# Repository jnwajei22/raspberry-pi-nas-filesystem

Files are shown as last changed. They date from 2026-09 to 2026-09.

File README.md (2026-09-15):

# Raspberry Pi NAS Filesystem

A custom Raspberry Pi 4-based network attached storage system built around a 3D-printed enclosure, a custom USB-to-NVMe carrier PCB, and 4 TB of M.2 NVMe storage.

The goal of this project is to build a compact personal file server from the enclosure up rather than relying on a prebuilt NAS chassis or external SSD enclosure.

## Project Goals

- Raspberry Pi 4B-based NAS
- 4 TB M.2 2280 NVMe storage
- Custom 90 × 90 mm USB-to-NVMe carrier PCB
- USB 3.x connection between the Raspberry Pi and storage board
- Custom 3D-printed enclosure
- Internal mounting system for the Raspberry Pi, storage board, and cooling hardware
- Active cooling
- Small system-status display
- Local monitoring of:
  - CPU temperature
  - CPU usage
  - RAM usage
  - SSD usage
  - SSD temperature and health
  - Read/write activity
  - Network throughput
  - IP address
  - System uptime
  - File-transfer progress

## System Architecture

```text
                  ┌─────────────────────┐
                  │   Raspberry Pi 4B   │
                  │                     │
                  │   NAS / monitoring  │
                  └──────────┬──────────┘
                             │
                          USB 3.x
                             │
                             ▼
                  ┌─────────────────────┐
                  │ Custom NVMe Carrier │
                  │     90 × 90 mm      │
                  │                     │
                  │ USB-C               │
                  │   │                 │
                  │   ▼                 │
                  │ JMS583 Bridge       │
                  │   │                 │
                  │   ▼ PCIe Gen3 ×2    │
                  │ M.2 M-Key Socket    │
                  │   │                 │
                  │   ▼                 │
                  │ 4 TB NVMe SSD       │
                  └─────────────────────┘
```

## Hardware

### Raspberry Pi

The system is based on a Raspberry Pi 4B.

The Pi handles:

- network file sharing
- storage management
- system monitoring
- status-display output
- fan control
- file-transfer monitoring

### Storage

The original concept used raw NAND flash with a custom SSD controller. That architecture was replaced with a standard M.2 NVMe SSD to reduce firmware, NAND-management, and supply-chain complexity.

The current design uses:

- standard M.2 2280 form factor
- M-key NVMe SSD
- target capacity: 4 TB
- PCIe-to-USB bridge
- USB 3.x connection to Raspberry Pi 4B

### Custom NVMe Carrier PCB

Target specifications:

| Parameter | Specification |
|---|---|
| Board size | 90 × 90 mm |
| Layers | 4 |
| SSD | M.2 2280 NVMe |
| Interface | PCIe Gen3 ×2 to USB 3.x |
| Host connector | USB-C |
| SSD power | 3.3 V |
| Input power | 5 V |
| Auxiliary power | Optional 5 V input |

Current primary components:

| Function | Part |
|---|---|
| USB/NVMe bridge | JMicron JMS583 |
| M.2 socket | TE Connectivity 1-2199230-6 |
| USB-C receptacle | Molex 2024100002 |
| SSD regulator | TI TPS54302 |
| SPI configuration flash | Winbond W25Q40JV |
| High-speed ESD protection | TI TPD4E05U06 |
| Bridge clock | 25 MHz crystal |

The PCB is being designed in Autodesk Fusion Electronics.

## Enclosure

The enclosure was designed from scratch in Autodesk Fusion.

The design includes:

- Raspberry Pi mounting
- internal mounting plate
- upper hardware level
- SSD carrier PCB mounting
- ventilation on multiple enclosure walls
- active cooling
- removable lid
- locating lip for lid alignment
- provision for a front-mounted system-status display

The enclosure is intended to be fully 3D printed.

Source CAD and manufacturing exports are stored under:

```text
hardware/enclosure/
```

## Repository Structure

```text
raspberry-pi-nas-filesystem/
├── README.md
│
├── hardware/
│   ├── pcb/
│   │   ├── schematic/
│   │   ├── board/
│   │   ├── bom/
│   │   └── fabrication/
│   │
│   └── enclosure/
│       ├── fusion/
│       ├── exports/
│       │   ├── step/
│       │   ├── stl/
│       │   └── 3mf/
│       ├── drawings/
│       └── print-settings/
│
├── software/
│   ├── display/
│   ├── monitoring/
│   └── nas/
│
└── docs/
```

## Current Status

- [x] Raspberry Pi 4B selected
- [x] Enclosure concept completed
- [x] Internal mounting system modeled
- [x] Ventilation modeled
- [x] Main enclosure sent to print
- [x] Storage architecture selected
- [x] 4 TB M.2 NVMe target selected
- [x] Custom 90 × 90 mm carrier PCB architecture selected
- [ ] NVMe carrier schematic
- [ ] PCB layout
- [ ] PCB fabrication
- [ ] SSD installation
- [ ] Enclosure assembly
- [ ] Cooling installation
- [ ] Status display installation
- [ ] NAS operating-system configuration
- [ ] Monitoring software
- [ ] File-transfer progress display
- [ ] Final testing

## Design Philosophy

The project is intentionally designed as a complete engineering system rather than a collection of off-the-shelf modules.

Where practical, mechanical structure, mounting hardware, electronics, and software are being designed together so that the final system behaves as a single integrated device.

At the same time, standard components such as the Raspberry Pi and M.2 NVMe SSD are used where designing replacements would add significant complexity without improving the final NAS.

## Software

Planned software functions include:

- SMB/NFS file sharing
- storage-health monitoring
- NVMe SMART telemetry
- CPU and memory monitoring
- network throughput monitoring
- fan status/control
- local status-display interface
- transfer-progress visualization

Software development will be added after the mechanical and storage hardware are validated.

## CAD and Manufacturing Files

The repository will contain both editable source files and manufacturing exports.

For the enclosure:

- Fusion source files
- STEP files
- STL files
- 3MF files
- drawings
- print settings

For the PCB:

- Fusion Electronics schematic
- board layout
- BOM
- Gerbers
- drill files
- fabrication notes

## Revision

Current hardware revision:

```text
Enclosure: Rev A
NVMe Carrier PCB: Rev A
```

## Author

Justin Nwajei

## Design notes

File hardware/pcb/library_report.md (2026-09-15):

# KiCad library preparation report

Prepared 2026-09-14 and corrective-review updated 2026-09-15. The reviewed schematic is under `hardware/pcb/kicad/`.

All usable symbols, footprints, and 3D models are stored under `hardware/pcb/libraries/`. The project-local `sym-lib-table` and `fp-lib-table` use `${KIPRJMOD}` paths and do not reference global computer paths.

## Acquisition and verification status

| Part number | Manufacturer | Symbol source | Footprint source | Datasheet source | Exact-match status | Verification status | Notes |
|---|---|---|---|---|---|---|---|
| JMS583-QHFA0A | JMicron | **CUSTOM-VERIFY**, drawn from the public JMicron JMS583 Rev. 2.1 signal table | Exact EasyEDA/LCSC record C9900110183, component UUID `7ed4b3711810454eb69c8505d68afa0a`, footprint UUID `2eb720523592401281967fab13173877`; converted to KiCad | [JMicron JMS583 Rev. 2.1 public datasheet](https://snapeda.s3.amazonaws.com/datasheets/2115-PDS-17001_JMS583_Datasheet_(Rev._2.1)_20190716.pdf); local copy `libraries/datasheets/JMicron_JMS583_datasheet_rev2.1.pdf` | YES for ordering code and exact distributor CAD record | **CUSTOM-VERIFY** | Symbol has pins 1-64 plus exposed pad 65. Footprint is QFN-64, 8.0 x 8.0 mm, 0.40 mm pitch, with 4.5 x 4.5 mm exposed pad 65 and 65 total pads. Pin 65 is explicitly grounded in the corrected schematic. Exact converted STEP is local. |
| 2024100002 | Molex | Official KiCad `USB_C_Receptacle` pin model adapted to the exact MPN and local footprint | Exact EasyEDA/LCSC C586089 CAD, converted to KiCad | [Molex exact product page](https://www.molex.com/en-us/products/part-detail/2024100002), [customer drawing 2024100002](https://www.molex.com/content/dam/molex/molex-dot-com/products/automated/en-us/salesdrawingpdf/202/202410/2024100002_sd.pdf) | YES | **CUSTOM-VERIFY symbol; VERIFIED footprint** | 24 USB-C contacts A1-A12/B1-B12 at 0.50 mm pitch. Four shell/retention pads are all numbered `S1` to match the symbol shield pin. Mid-mount outline, connector orientation, shell holes/tabs, and 0.60/0.70 mm PCB-thickness callout were checked. Exact converted STEP is local. |
| 1-2199230-6 | TE Connectivity | Official KiCad `Bus_M.2_Socket_M` adapted to exact MPN; explicit `SH1`/`SH2` shield pins added | Exact EasyEDA/LCSC C4710843 CAD, converted to KiCad | [TE exact product page](https://www.te.com/fr/product-1-2199230-6.html), [TE customer drawing mirror](https://www.farnell.com/cad/1918022.pdf) | YES | **CUSTOM-VERIFY symbol; VERIFIED footprint** | M-key, 67 signal contacts: 1-58 and 67-75, 0.50 mm pitch; 2 SMD shield tabs `SH1`/`SH2`; 2 unnumbered NPTH locator holes. Keying, orientation, 21.9 x 8.7 x 4.2 mm product envelope, and mounting features checked. Exact converted STEP is local. |
| TPS54302DDCR | Texas Instruments | Official KiCad `TPS54302`, adapted to exact ordering code and local footprint | Official KiCad `SOT-23-6`, copied locally as `TPS54302DDCR_DDC0006A` | [TI exact part page](https://www.ti.com/product/TPS54302/part-details/TPS54302DDCR), [TI TPS54302 datasheet](https://www.ti.com/lit/ds/symlink/tps54302.pdf); local copy `libraries/datasheets/TI_TPS54302_datasheet.pdf` | YES | **VERIFIED** | Pins verified: 1 GND, 2 SW, 3 VIN, 4 FB, 5 EN, 6 BOOT. DDC0006A/SOT-23-6 has 6 pads, 0.95 mm pitch, no exposed pad. Official KiCad package STEP is copied locally. |
| W25Q16JVSNIQ (tape/reel order option `W25Q16JVSNIQ TR`) | Winbond | Official KiCad W25Q-JV pin model, flattened and adapted to the exact orderable package suffix | Official KiCad `SOIC-8_3.9x4.9mm_P1.27mm`, copied locally as `Winbond_W25Q16JVSNIQ_SOIC8_150mil` | [Winbond W25Q16JV documentation](https://www.winbond.com/hq/support/documentation/levelOne.jsp?__locale=en&DocNo=DA00-W25Q16JV.1), [Winbond W25Q-JV family](https://www.winbond.com/hq/product/code-storage-flash/qspi-nor/w25q-jv/?__locale=en), [active stocked tape/reel listing](https://www.digikey.com/en/products/detail/winbond-electronics/W25Q16JVSNIQ-TR/10238303) | YES | **VERIFIED** | Replaces invalid `W25Q40JVSSIQ`. 16 Mbit / 2 MiB, 2.7-3.6 V, SPI/Dual/Quad SPI, SOIC-8 150 mil, -40 to +85 C. Pins: 1 CS#, 2 DO/IO1, 3 WP#/IO2, 4 GND, 5 DI/IO0, 6 CLK, 7 HOLD#/RESET#/IO3, 8 VCC. Eight pads, 1.27 mm pitch, 3.9 x 4.9 mm body, no exposed pad. The older 8 Mbit JV SOIC and the 208 mil W25Q16JVSSIQ were rejected because they are marked obsolete; the W25Q16JVSNIQ tape/reel listing is active and stocked. |
| TPD4E05U06DQAR | Texas Instruments | Official KiCad `TPD4EUSB30` pin-compatible device symbol adapted to the exact MPN | Official KiCad `USON-10_2.5x1.0mm_P0.5mm`, copied locally as `TPD4E05U06DQAR_DQA0010A` | [TI exact part page](https://www.ti.com/product/TPD4E05U06/part-details/TPD4E05U06DQAR), [TI TPD4E05U06 datasheet](https://www.ti.com/lit/ds/symlink/tpd4e05u06.pdf); local copy `libraries/datasheets/TI_TPD4E05U06_datasheet.pdf` | YES | **VERIFIED with package-construction note** | Pins verified: 1 D1+, 2 D1-, 3 GND, 4 D2+, 5 D2-, 6 NC, 7 NC, 8 GND, 9 NC, 10 NC. DQA is USON-10, 2.5 x 1.0 mm, 0.50 mm pitch, 10 pads, no center exposed pad in DQA0010A. Official KiCad package STEP is copied locally. |
| ABM8-25.000MHZ-B2-T | Abracon | Official KiCad `Crystal_GND24` adapted to the exact MPN and local footprint | Exact EasyEDA/LCSC C596899 CAD, converted to KiCad | [Abracon ABM8 datasheet](https://abracon.com/Resonators/abm8.pdf); local copy `libraries/datasheets/Abracon_ABM8_datasheet.pdf` | YES | **CUSTOM-VERIFY symbol; VERIFIED footprint** | Four pads: 1/3 crystal electrodes and 2/4 case ground. Verified 3.2 x 2.5 x 0.8 mm body and recommended pads 1.4 x 1.2 mm centered at +/-1.10 mm X and +/-0.85 mm Y. Exact converted STEP is local. |

## Verification details

### Symbol pin checks

- `JMicron_JMS583-QHFA0A`: checked all numbered pins 1-64 against the Rev. 2.1 signal table, including USB SuperSpeed pairs (`U_TXP/N1`, `U_TXP/N2`, `U_RXP/N1`, `U_RXP/N2`), PCIe pairs (`P_TXP/N0`, `P_TXP/N1`, `P_RXP/N0`, `P_RXP/N1`), USB 2.0 `DP`/`DM`, `CLKP`/`CLKN`, `CC1`/`CC2`, rails, reset, GPIO, crystal, and regulator pins. Pad 65 is exposed as `EP` so the footprint cannot silently contain an unmapped electrical pad.
- `Molex_2024100002`: verified the complete reversible USB-C receptacle pin set A1-A12/B1-B12, duplicated VBUS/GND pins, USB 2.0 D+/D- pins, SuperSpeed TX/RX pairs, CC1/CC2, SBU1/SBU2, and shield.
- `TE_1-2199230-6`: verified M-key contact numbering and omitted key positions. Both footprint shell pads are now explicit passive symbol pins `SH1` and `SH2`.
- `TPS54302DDCR`, `TPD4E05U06DQAR`, and `ABM8-25.000MHZ-B2-T`: pin numbers and functions match the manufacturer pin diagrams/tables summarized above.
- `W25Q16JVSNIQ`: verified against the Winbond pin diagram and official KiCad model: 1 CS#, 2 DO/IO1, 3 WP#/IO2, 4 GND, 5 DI/IO0, 6 CLK, 7 HOLD#/RESET#/IO3, and 8 VCC.

### Footprint mechanical checks

| Local footprint | Pad records | Mechanical verification |
|---|---:|---|
| `JMicron_JMS583-QHFA0A.kicad_mod` | 65 | QFN-64, 16 perimeter pads per side, 0.40 mm pitch, 8 x 8 mm body, center exposed pad 65 |
| `Molex_2024100002.kicad_mod` | 28 | 24 signal contacts plus four shell/retention tabs; exact mid-mount cutout and locator features retained |
| `TE_1-2199230-6_M2_M_Key.kicad_mod` | 71 | 67 signal contacts, two shield tabs, and two unnumbered NPTH locator holes; M-key gap retained |
| `TPS54302DDCR_DDC0006A.kicad_mod` | 6 | TI DDC/SOT-23-6, 0.95 mm pitch, no exposed pad |
| `TPD4E05U06DQAR_DQA0010A.kicad_mod` | 10 | TI DQA0010A USON-10, 2.5 x 1.0 mm, 0.50 mm pitch |
| `Abracon_ABM8-25.000MHZ-B2-T.kicad_mod` | 4 | 3.2 x 2.5 mm crystal, correct four-pad geometry and pin-1 marker |
| `Winbond_W25Q16JVSNIQ_SOIC8_150mil.kicad_mod` | 8 | SOIC-8 150 mil, 3.9 x 4.9 mm body, 1.27 mm pitch, no exposed pad; pad 1 marker retained |

## Sources and provenance

- Generic symbol/package bases are from the installed KiCad 9 official libraries and were copied into this repository: [KiCad symbols](https://gitlab.com/kicad/libraries/kicad-symbols) and [KiCad footprints](https://gitlab.com/kicad/libraries/kicad-footprints).
- Exact distributor CAD for JMS583-QHFA0A, 2024100002, 1-2199230-6, and ABM8-25.000MHZ-B2-T was converted to native KiCad format. Exact source UUID records retained for JMS583 are in `libraries/datasheets/source_records/`.
- Every footprint's 3D reference uses `${KIPRJMOD}/../libraries/3dmodels/...` from the requested `hardware/pcb/kicad/` project directory; no global KiCad or arbitrary machine path is used.

## Uncertainties and release gates

1. **JMS583 exposed pad:** pin 65 `EP` is explicitly connected to GND, matching the grounded center pad used by the available JMS583 package/reference guidance. This connection must be implemented with an appropriate thermal/via structure during layout.
2. **TPD4E05U06 DQA construction:** TI documents DQA0010A and DQA0010B package constructions for this orderable part. The local footprint is explicitly DQA0010A. TI support describes the constructions as interchangeable, but DQA0010B bridges the two GND lead regions. Confirm assembly-land-pattern acceptance if the fabricator requires construction-specific paste/copper details: [TI package discussion](https://e2e.ti.com/support/interface-group/interface/f/interface-forum/1384139/tpd4e05u06-what-is-the-correct-package-drawing).
3. **JMS583 application circuits:** the corrective review now uses 1.0 V for every VCCK/AVDDL pin, a 4.7 uH LXO inductor, a 330 kΩ/1 uF reset RC, 30 pF crystal loads plus 510 kΩ XIN-XOUT bias, grounded TME/EPAD, a GPIO4 active-low LED, and a GPIO6 VBUS divider. Crystal parasitics and final passive selections remain release checks.
4. **M.2 connector ERC typing repair:** signal pins on the adapted connector were changed from input/output/bidirectional to passive. Pin names, pin numbers, keying and footprint pads are unchanged. This correctly models a connector and removes false driver conflicts.
5. Symbols labeled **CUSTOM-VERIFY** were created or adapted from public documentation because a directly downloadable, authoritative exact-MPN KiCad symbol was not available. They have been checked as documented but should receive an independent engineering review before fabrication.

## Final status

- **Exact libraries acquired:** JMS583-QHFA0A, Molex 2024100002, TE 1-2199230-6, TPS54302DDCR, TPD4E05U06DQAR, and Abracon ABM8-25.000MHZ-B2-T.
- **Flash substitution:** invalid `W25Q40JVSSIQ` replaced by verified, active/stocked tape-reel `W25Q16JVSNIQ`.
- **Parts missing:** none among the seven required exact parts.
- **Custom libraries created/adapted and labeled CUSTOM-VERIFY:** JMS583-QHFA0A symbol; Molex 2024100002 symbol adaptation; TE 1-2199230-6 symbol adaptation including shield pins; Abracon ABM8-25.000MHZ-B2-T symbol adaptation.
- **Pinout/package uncertainties:** TPD4E05U06 DQA0010A versus DQA0010B construction remains; JMS583 EPAD is now explicitly grounded and its thermal/via implementation remains a layout requirement.
- **Repository-local KiCad tables ready:** YES. The project tables in `hardware/pcb/kicad/` use `${KIPRJMOD}/../libraries/...`; the library-root tables remain valid for `hardware/pcb/`.
- **Library parser validation:** KiCad 9.0.5 successfully exported the W25Q16JVSNIQ symbol and footprint to SVG.
- **Schematic validation:** after the 2026-09-15 corrective review, KiCad 9.0.5 parses and exports netlist/BOM/PDF/SVG and reports **0 ERC errors and 0 ERC warnings**.

## Corrected schematic summary

The single A3 schematic is divided into four labeled sections: USB interface, JMS583 bridge, NVMe/M.2, and power. It contains the exact USB-C receptacle, JMS583, M.2 socket, TPS54302, crystal, flash and three TPD4E05U06 arrays. Four 100 nF capacitors couple the JMS583 USB transmitter pairs, and four 220 nF capacitors couple the JMS583 PCIe transmit lanes. Only PCIe lanes 0 and 1 are connected; lanes 2 and 3 are explicitly unconnected. The ESD arrays are shunt branches from continuous connector-side USB nets and are not series elements.

The former U5 power-mux placeholder has been removed. `USB5V` powers the JMS583 VDDREG/VBUS side and its internally generated 3.3 V/1.0 V rails; `AUX5V` independently powers the TPS54302 and NVMe 3.3 V rail; grounds are common. AUX5V/3V3_NVME must be ready before enumeration when SSD access is required. The TPS54302 network retains TI's 3.3 V starting values: 6.8 uH, 44 uF nominal output capacitance, 100 kΩ / 22.1 kΩ feedback and 47 pF feed-forward. The regulator's 3 A maximum is a release gate until the 4 TB SSD is selected.

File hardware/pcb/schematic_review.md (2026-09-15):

# Corrective schematic review

Reviewed and regenerated 2026-09-15. Scope is schematic only; no PCB layout was created or started.

## Validation result

- KiCad version: 9.0.5
- ERC: 0 errors, 0 warnings (`kicad/erc.json`)
- Netlist export: successful (`kicad/raspberry_pi_nas_nvme.net`)
- BOM export: successful (`kicad/raspberry_pi_nas_nvme_bom.csv`)
- PDF export: successful (`kicad/raspberry_pi_nas_nvme_review.pdf`)
- SVG export: successful (`kicad/raspberry_pi_nas_nvme.svg`)

## 1. JMS583 supply correction

The incorrect `1V2_JMS` rail was removed everywhere and replaced by `1V0_JMS`.

| JMS583 pins | Function | Corrected net |
|---|---|---|
| 2, 31, 53 | VCCK, digital core | `1V0_JMS` |
| 20, 25, 30, 33, 36, 40, 43, 46, 49 | AVDDL, analog core | `1V0_JMS` |
| 6, 11, 32, 56 | VCCO, 3.3 V I/O | `3V3_JMS` |
| 52 | XAVDDH, crystal pad supply | `3V3_JMS` |
| 64 | LXO switching node | `JMS_LXO` → L1 4.7 µH → `1V0_JMS` |
| 1 | VDDREG, internal-regulator 5 V input | `USB5V` |
| 19 | AVDD33, internal 3.3 V output | `3V3_JMS` |

The 1.0 V bypass network is C8 = 100 nF, C9 = 1 µF and C10 = 4.7 µF. Final distribution and per-pin capacitor placement must be completed during layout.

## 2. Reset RC

The former pull-up-only reset was electrically incomplete. RST pin 15 now has:

- R2 = 330 kΩ, 1%, from `3V3_JMS` to `JMS_RST_N`
- C26 = 1 µF, X7R, 10%, from `JMS_RST_N` to GND

The JMS583 datasheet defines T4 as the RST rise time from 0 V to 1.77 V and requires 120–500 ms for an RC implementation. For a 3.3 V exponential charge:

`t = -RC × ln(1 - 1.77/3.3) = 0.768RC`

Nominally, `t = 0.768 × 330 kΩ × 1 µF = 254 ms`. With the stated resistor and capacitor tolerances, the component-tolerance range is approximately 226–282 ms, inside the documented 120–500 ms interval. Capacitor leakage and effective capacitance must be checked when selecting the exact C26 MPN.

## 3. Crystal network

Y1 remains the ABM8-25.000MHZ-B2-T: 25 MHz, specified load capacitance 18 pF. The completed network is:

- C24 = 30 pF C0G 5% from XIN to GND
- C25 = 30 pF C0G 5% from XOUT to GND
- R8 = 510 kΩ from XIN to XOUT, following the JMS583 reference topology
- Crystal case pads 2 and 4 to GND

For equal load capacitors, `CL = C/2 + Cstray`. Using a documented design assumption of 3 pF combined IC-pin/trace/land stray capacitance gives `CL = 30/2 + 3 = 18 pF`. This is a calculated starting network, not an arbitrary value. Actual parasitics depend on placement and routing, so C24/C25 must be revisited using extracted or measured board parasitics before release.

## 4. USB ESD audit

The existing TPD4E05U06 signal implementation was **not electrically wrong**. Each channel was already a shunt branch from a signal net to the ESD device, with pins 3 and 8 grounded. No ESD device was placed in series. The corrected schematic preserves that topology.

| Protected net | Continuous signal path | ESD branch |
|---|---|---|
| `USB_TX1_P/N` | J1 A2/A3 directly to U1 U_RXP1/U_RXN1 pins 26/27 | U2 pins 1/2 |
| `USB_TX2_P/N` | J1 B2/B3 directly to U1 U_RXP2/U_RXN2 pins 29/28 | U3 pins 1/2 |
| `USB_RX1_P/N` | J1 B11/B10 to C1/C2; capacitor inner nets go to U1 U_TXP1/U_TXN1 pins 21/22 | U2 pins 4/5 on connector side |
| `USB_RX2_P/N` | J1 A11/A10 to C3/C4; capacitor inner nets go to U1 U_TXP2/U_TXN2 pins 24/23 | U3 pins 4/5 on connector side |
| `USB_DP/DM` | J1 A6/B6 and A7/B7 directly to U1 DP/DM pins 18/17 | U4 pins 1/2 |

U4's unused channels are no-connect. All three devices connect both ground pins, 3 and 8, to common GND. The physical placement/routing requirement remains: place the ESD arrays close to J1 with a short, low-inductance ground return and avoid stubs on the SuperSpeed pairs.

## 5. Split power architecture

The unresolved U5 power-mux placeholder was removed. The schematic now implements:

- `USB5V` from J1 powers JMS583 VDDREG pin 1 and VBUS pin 16.
- The JMS583 generates its local `3V3_JMS` and `1V0_JMS` rails.
- `AUX5V` from J2 powers TPS54302 VIN and EN plus its input capacitors.
- TPS54302 generates `3V3_NVME` only for the M.2/NVMe load.
- USB and auxiliary supplies share GND but are not tied together on their positive rails.

This split is valid provided AUX5V and `3V3_NVME` are stable when the bridge enumerates and attempts to discover the SSD. If AUX5V can arrive later than USB5V, system-level sequencing or a re-enumeration/reset policy is required.

USB cable presence is handled in both documented ways: U1 VBUS pin 16 is tied to USB5V, and GPIO6 pin 10 receives `USB_VBUS_SENSE` through a 100 kΩ/100 kΩ divider. The nominal GPIO6 level is 2.5 V at 5.0 V VBUS.

## 6. PCIe topology

PCIe lanes 0 and 1 remain connected for x2 operation. Lanes 2 and 3 remain intentionally unconnected. C11–C14 remain 220 nF series capacitors on the two JMS583 PCIe transmit differential pairs. No topology change was made.

## 7. TPS54302 review

The TI 3.3 V starting network remains unchanged:

- L2 = 6.8 µH
- C20 + C21 = 44 µF nominal output capacitance
- R6/R7 = 100 kΩ / 22.1 kΩ
- C19 = 47 pF feed-forward

The TPS54302's 3 A maximum is a release gate. The actual 4 TB NVMe SSD must be selected and its startup, peak and transient current verified before release. Effective ceramic output capacitance under 3.3 V DC bias must also meet the regulator stability/transient requirements.

## 8. EPAD and test mode

- U1 exposed pad pin 65 is explicitly tied to GND.
- U1 ground pin 63 is tied to GND.
- U1 TME pin 60 is tied to GND, holding test mode at logic 0 for normal operation.

The eventual layout must use the exposed-pad copper/via pattern required for electrical grounding and thermal performance.

## 9. Activity LED correction

The previous schematic was electrically wrong here: D1 was connected to GPIO12, pin 57. It is now connected to the documented default LED output, GPIO4 pin 8.

The corrected active-low sink path is `3V3_JMS → R3 (1 kΩ) → D1 anode → D1 cathode → GPIO4`. GPIO12 is no-connect. The exact LED MPN and brightness remain component-selection items.

## Remaining release gates

- Select the exact J2 connector and define the AUX5V source requirements.
- Select and derate every generic passive, inductor and LED.
- Confirm reset-capacitor leakage/effective capacitance with the selected MPN.
- Extract or measure the crystal network parasitics and tune C24/C25 if necessary.
- Define system sequencing behavior if AUX5V can be absent or late relative to USB5V.
- Select the 4 TB NVMe SSD and verify the TPS54302 3 A limit and transient response.

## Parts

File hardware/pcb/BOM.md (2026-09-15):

# Raspberry Pi NAS NVMe schematic BOM

Corrected schematic BOM for `hardware/pcb/kicad/raspberry_pi_nas_nvme.kicad_sch`, reviewed 2026-09-15. Quantities are per board. Generic passives retain package/value assignments but require final manufacturer-part selection and derating before PCB release.

## Exact and major parts

| References | Qty | Manufacturer | Manufacturer part number | Description | Footprint | Status |
|---|---:|---|---|---|---|---|
| U1 | 1 | JMicron | JMS583-QHFA0A | USB 3.x to PCIe/NVMe bridge | `RaspberryPiNAS:JMicron_JMS583-QHFA0A` | Exact; corrected 1.0 V rails, reset, crystal, VBUS sense, GPIO4 LED, TME and EPAD connections |
| J1 | 1 | Molex | 2024100002 | Full-featured USB-C receptacle | `RaspberryPiNAS:Molex_2024100002` | Exact, verified orientation/keying |
| J3 | 1 | TE Connectivity | 1-2199230-6 | 67-contact M.2 M-key socket | `RaspberryPiNAS:TE_1-2199230-6_M2_M_Key` | Exact, verified; PCIe Gen3 x2 electrically |
| U7 | 1 | Texas Instruments | TPS54302DDCR | 3 A synchronous buck regulator | `RaspberryPiNAS:TPS54302DDCR_DDC0006A` | Exact; AUX5V-powered 3.3 V NVMe supply |
| U2-U4 | 3 | Texas Instruments | TPD4E05U06DQAR | Four-channel low-capacitance shunt ESD array | `RaspberryPiNAS:TPD4E05U06DQAR_DQA0010A` | Exact; branched from continuous USB nets, never used in series |
| U6 | 1 | Winbond | W25Q16JVSNIQ TR | 16 Mbit, 3 V SPI/Dual/Quad NOR flash | `RaspberryPiNAS:Winbond_W25Q16JVSNIQ_SOIC8_150mil` | Exact verified replacement for invalid W25Q40JVSSIQ |
| Y1 | 1 | Abracon | ABM8-25.000MHZ-B2-T | 25 MHz, 18 pF load crystal | `RaspberryPiNAS:Abracon_ABM8-25.000MHZ-B2-T` | Exact; 30 pF calculated load capacitors and 510 kΩ bias resistor added |
| D1 | 1 | TBD | TBD | Green activity LED | `LED_SMD:LED_0603_1608Metric_Pad1.05x0.95mm_HandSolder` | Active-low: 3V3_JMS → R3 → anode/cathode → JMS583 GPIO4 |
| J2 | 1 | TBD | TBD | Auxiliary 5 V input connector | No footprint assigned | Powers only the TPS54302/NVMe rail; connector selection remains open |

## Resistors

| References | Qty | Value | Function | Footprint/status |
|---|---:|---|---|---|
| R1 | 1 | 12 kΩ, 1% | JMS583 REXT | 0603; documented value |
| R2 | 1 | 330 kΩ, 1% | JMS583 active-low reset pull-up | 0603; with C26 gives 254 ms nominal to 1.77 V |
| R3 | 1 | 1 kΩ | GPIO4 activity LED current limiting | 0603; active-low sink arrangement |
| R4-R5 | 2 | 10 kΩ | Flash WP#/HOLD# pull-ups | 0603 |
| R6 | 1 | 100 kΩ, 1% | TPS54302 upper feedback resistor | 0603; TI 3.3 V starting value |
| R7 | 1 | 22.1 kΩ, 1% | TPS54302 lower feedback resistor | 0603; TI 3.3 V starting value |
| R8 | 1 | 510 kΩ | Crystal XIN-to-XOUT bias/feedback | 0603; follows the JMS583 reference topology |
| R9-R10 | 2 | 100 kΩ, 1% | USB VBUS divider to GPIO6 | 0603; 5 V produces nominal 2.5 V sense level |

## Capacitors and inductors

| References | Qty | Value | Function | Footprint/status |
|---|---:|---|---|---|
| C1-C4 | 4 | 100 nF | JMS583 USB TX AC coupling | 0603; retained |
| C5, C8 | 2 | 100 nF | JMS583 3.3 V / 1.0 V high-frequency bypass | 0603 |
| C6, C9 | 2 | 1 µF | JMS583 3.3 V / 1.0 V local bypass | 0603 |
| C7, C10 | 2 | 4.7 µF | JMS583 3.3 V / 1.0 V bulk bypass | 0603; verify DC bias |
| C11-C14 | 4 | 220 nF | JMS583 PCIe TX coupling, lanes 0/1 | 0603; retained |
| C15 | 1 | 10 µF | TPS54302 AUX5V input decoupling | 1210; select voltage/ripple rating |
| C16 | 1 | 100 nF | TPS54302 AUX5V high-frequency bypass | 0603 |
| C17 | 1 | 47 µF | AUX5V bulk | 1210 placeholder; select rated part |
| C18 | 1 | 100 nF | TPS54302 BOOT-SW | 0603 |
| C19 | 1 | 47 pF | TPS54302 feed-forward | 0603; TI 3.3 V starting value |
| C20-C21 | 2 | 22 µF | TPS54302 output, 44 µF nominal total | 1210; verify effective capacitance under DC bias |
| C22 | 1 | 100 µF | M.2 3.3 V bulk | 1210 placeholder; package/technology may need enlargement |
| C23 | 1 | 100 nF | M.2 local high-frequency bypass | 0603 |
| C24-C25 | 2 | 30 pF, C0G, 5% | 25 MHz crystal load | 0603; calculated for 18 pF CL with 3 pF combined parasitic assumption |
| C26 | 1 | 1 µF, X7R, 10% | JMS583 reset timing capacitor | 0603; use a low-leakage part with adequate effective capacitance |
| L1 | 1 | 4.7 µH | JMS583 LXO to 1V0_JMS regulator inductor | 1210; select current-rated MPN |
| L2 | 1 | 6.8 µH, ≥3 A | TPS54302 3.3 V buck | 1210 placeholder; select saturation/current-rated MPN |

## Release gates

- Select a rated AUX5V connector and define the required source voltage/current tolerance.
- Select manufacturer part numbers for passives, inductors and LED after voltage, DC-bias, leakage, ripple, saturation, tolerance and thermal checks.
- Measure or extract actual crystal pin/trace parasitics during layout and tune C24/C25 if the assumed 3 pF is not valid.
- Confirm AUX5V and 3V3_NVME sequencing is valid before USB enumeration in the finished system.
- Confirm the selected 4 TB NVMe SSD's peak and transient current is compatible with the TPS54302's 3 A maximum.

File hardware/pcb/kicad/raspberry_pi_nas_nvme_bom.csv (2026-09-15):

Refs | Value | Footprint | Qty | DNP
C1 | 100nF | Capacitor_SMD:C_0603_1608Metric_Pad1.08x0.95mm_HandSolder | 1
C2 | 100nF | Capacitor_SMD:C_0603_1608Metric_Pad1.08x0.95mm_HandSolder | 1
C3 | 100nF | Capacitor_SMD:C_0603_1608Metric_Pad1.08x0.95mm_HandSolder | 1
C4 | 100nF | Capacitor_SMD:C_0603_1608Metric_Pad1.08x0.95mm_HandSolder | 1
C5 | 100nF | Capacitor_SMD:C_0603_1608Metric_Pad1.08x0.95mm_HandSolder | 1
C6 | 1uF | Capacitor_SMD:C_0603_1608Metric_Pad1.08x0.95mm_HandSolder | 1
C7 | 4.7uF | Capacitor_SMD:C_0603_1608Metric_Pad1.08x0.95mm_HandSolder | 1
C8 | 100nF | Capacitor_SMD:C_0603_1608Metric_Pad1.08x0.95mm_HandSolder | 1
C9 | 1uF | Capacitor_SMD:C_0603_1608Metric_Pad1.08x0.95mm_HandSolder | 1
C10 | 4.7uF | Capacitor_SMD:C_0603_1608Metric_Pad1.08x0.95mm_HandSolder | 1
C11 | 220nF | Capacitor_SMD:C_0603_1608Metric_Pad1.08x0.95mm_HandSolder | 1
C12 | 220nF | Capacitor_SMD:C_0603_1608Metric_Pad1.08x0.95mm_HandSolder | 1
C13 | 220nF | Capacitor_SMD:C_0603_1608Metric_Pad1.08x0.95mm_HandSolder | 1
C14 | 220nF | Capacitor_SMD:C_0603_1608Metric_Pad1.08x0.95mm_HandSolder | 1
C15 | 10uF | Capacitor_SMD:C_1210_3225Metric_Pad1.33x2.70mm_HandSolder | 1
C16 | 100nF | Capacitor_SMD:C_0603_1608Metric_Pad1.08x0.95mm_HandSolder | 1
C17 | 47uF | Capacitor_SMD:C_1210_3225Metric_Pad1.33x2.70mm_HandSolder | 1
C18 | 100nF | Capacitor_SMD:C_0603_1608Metric_Pad1.08x0.95mm_HandSolder | 1
C19 | 47pF | Capacitor_SMD:C_0603_1608Metric_Pad1.08x0.95mm_HandSolder | 1
C20 | 22uF | Capacitor_SMD:C_1210_3225Metric_Pad1.33x2.70mm_HandSolder | 1
C21 | 22uF | Capacitor_SMD:C_1210_3225Metric_Pad1.33x2.70mm_HandSolder | 1
C22 | 100uF | Capacitor_SMD:C_1210_3225Metric_Pad1.33x2.70mm_HandSolder | 1
C23 | 100nF | Capacitor_SMD:C_0603_1608Metric_Pad1.08x0.95mm_HandSolder | 1
C24 | 30pF C0G 5% | Capacitor_SMD:C_0603_1608Metric_Pad1.08x0.95mm_HandSolder | 1
C25 | 30pF C0G 5% | Capacitor_SMD:C_0603_1608Metric_Pad1.08x0.95mm_HandSolder | 1
C26 | 1uF X7R 10% | Capacitor_SMD:C_0603_1608Metric_Pad1.08x0.95mm_HandSolder | 1
D1 | ACTIVITY GREEN | LED_SMD:LED_0603_1608Metric_Pad1.05x0.95mm_HandSolder | 1
J1 | 2024100002 | RaspberryPiNAS:Molex_2024100002 | 1
J2 | AUX5V INPUT — CONNECTOR TBD |  | 1
J3 | 1-2199230-6 | RaspberryPiNAS:TE_1-2199230-6_M2_M_Key | 1
L1 | 4.7uH | Inductor_SMD:L_1210_3225Metric_Pad1.42x2.65mm_HandSolder | 1
L2 | 6.8uH / >=3A | Inductor_SMD:L_1210_3225Metric_Pad1.42x2.65mm_HandSolder | 1
R1 | 12k 1% | Resistor_SMD:R_0603_1608Metric_Pad0.98x0.95mm_HandSolder | 1
R2 | 330k 1% | Resistor_SMD:R_0603_1608Metric_Pad0.98x0.95mm_HandSolder | 1
R3 | 1k | Resistor_SMD:R_0603_1608Metric_Pad0.98x0.95mm_HandSolder | 1
R4 | 10k | Resistor_SMD:R_0603_1608Metric_Pad0.98x0.95mm_HandSolder | 1
R5 | 10k | Resistor_SMD:R_0603_1608Metric_Pad0.98x0.95mm_HandSolder | 1
R6 | 100k 1% | Resistor_SMD:R_0603_1608Metric_Pad0.98x0.95mm_HandSolder | 1
R7 | 22.1k 1% | Resistor_SMD:R_0603_1608Metric_Pad0.98x0.95mm_HandSolder | 1
R8 | 510k | Resistor_SMD:R_0603_1608Metric_Pad0.98x0.95mm_HandSolder | 1
R9 | 100k 1% | Resistor_SMD:R_0603_1608Metric_Pad0.98x0.95mm_HandSolder | 1
R10 | 100k 1% | Resistor_SMD:R_0603_1608Metric_Pad0.98x0.95mm_HandSolder | 1
U1 | JMS583-QHFA0A | RaspberryPiNAS:JMicron_JMS583-QHFA0A | 1
U2 | TPD4E05U06DQAR | RaspberryPiNAS:TPD4E05U06DQAR_DQA0010A | 1
U3 | TPD4E05U06DQAR | RaspberryPiNAS:TPD4E05U06DQAR_DQA0010A | 1
U4 | TPD4E05U06DQAR | RaspberryPiNAS:TPD4E05U06DQAR_DQA0010A | 1
U6 | W25Q16JVSNIQ TR | RaspberryPiNAS:Winbond_W25Q16JVSNIQ_SOIC8_150mil | 1
U7 | TPS54302DDCR | RaspberryPiNAS:TPS54302DDCR_DDC0006A | 1
Y1 | ABM8-25.000MHZ-B2-T | RaspberryPiNAS:Abracon_ABM8-25.000MHZ-B2-T | 1

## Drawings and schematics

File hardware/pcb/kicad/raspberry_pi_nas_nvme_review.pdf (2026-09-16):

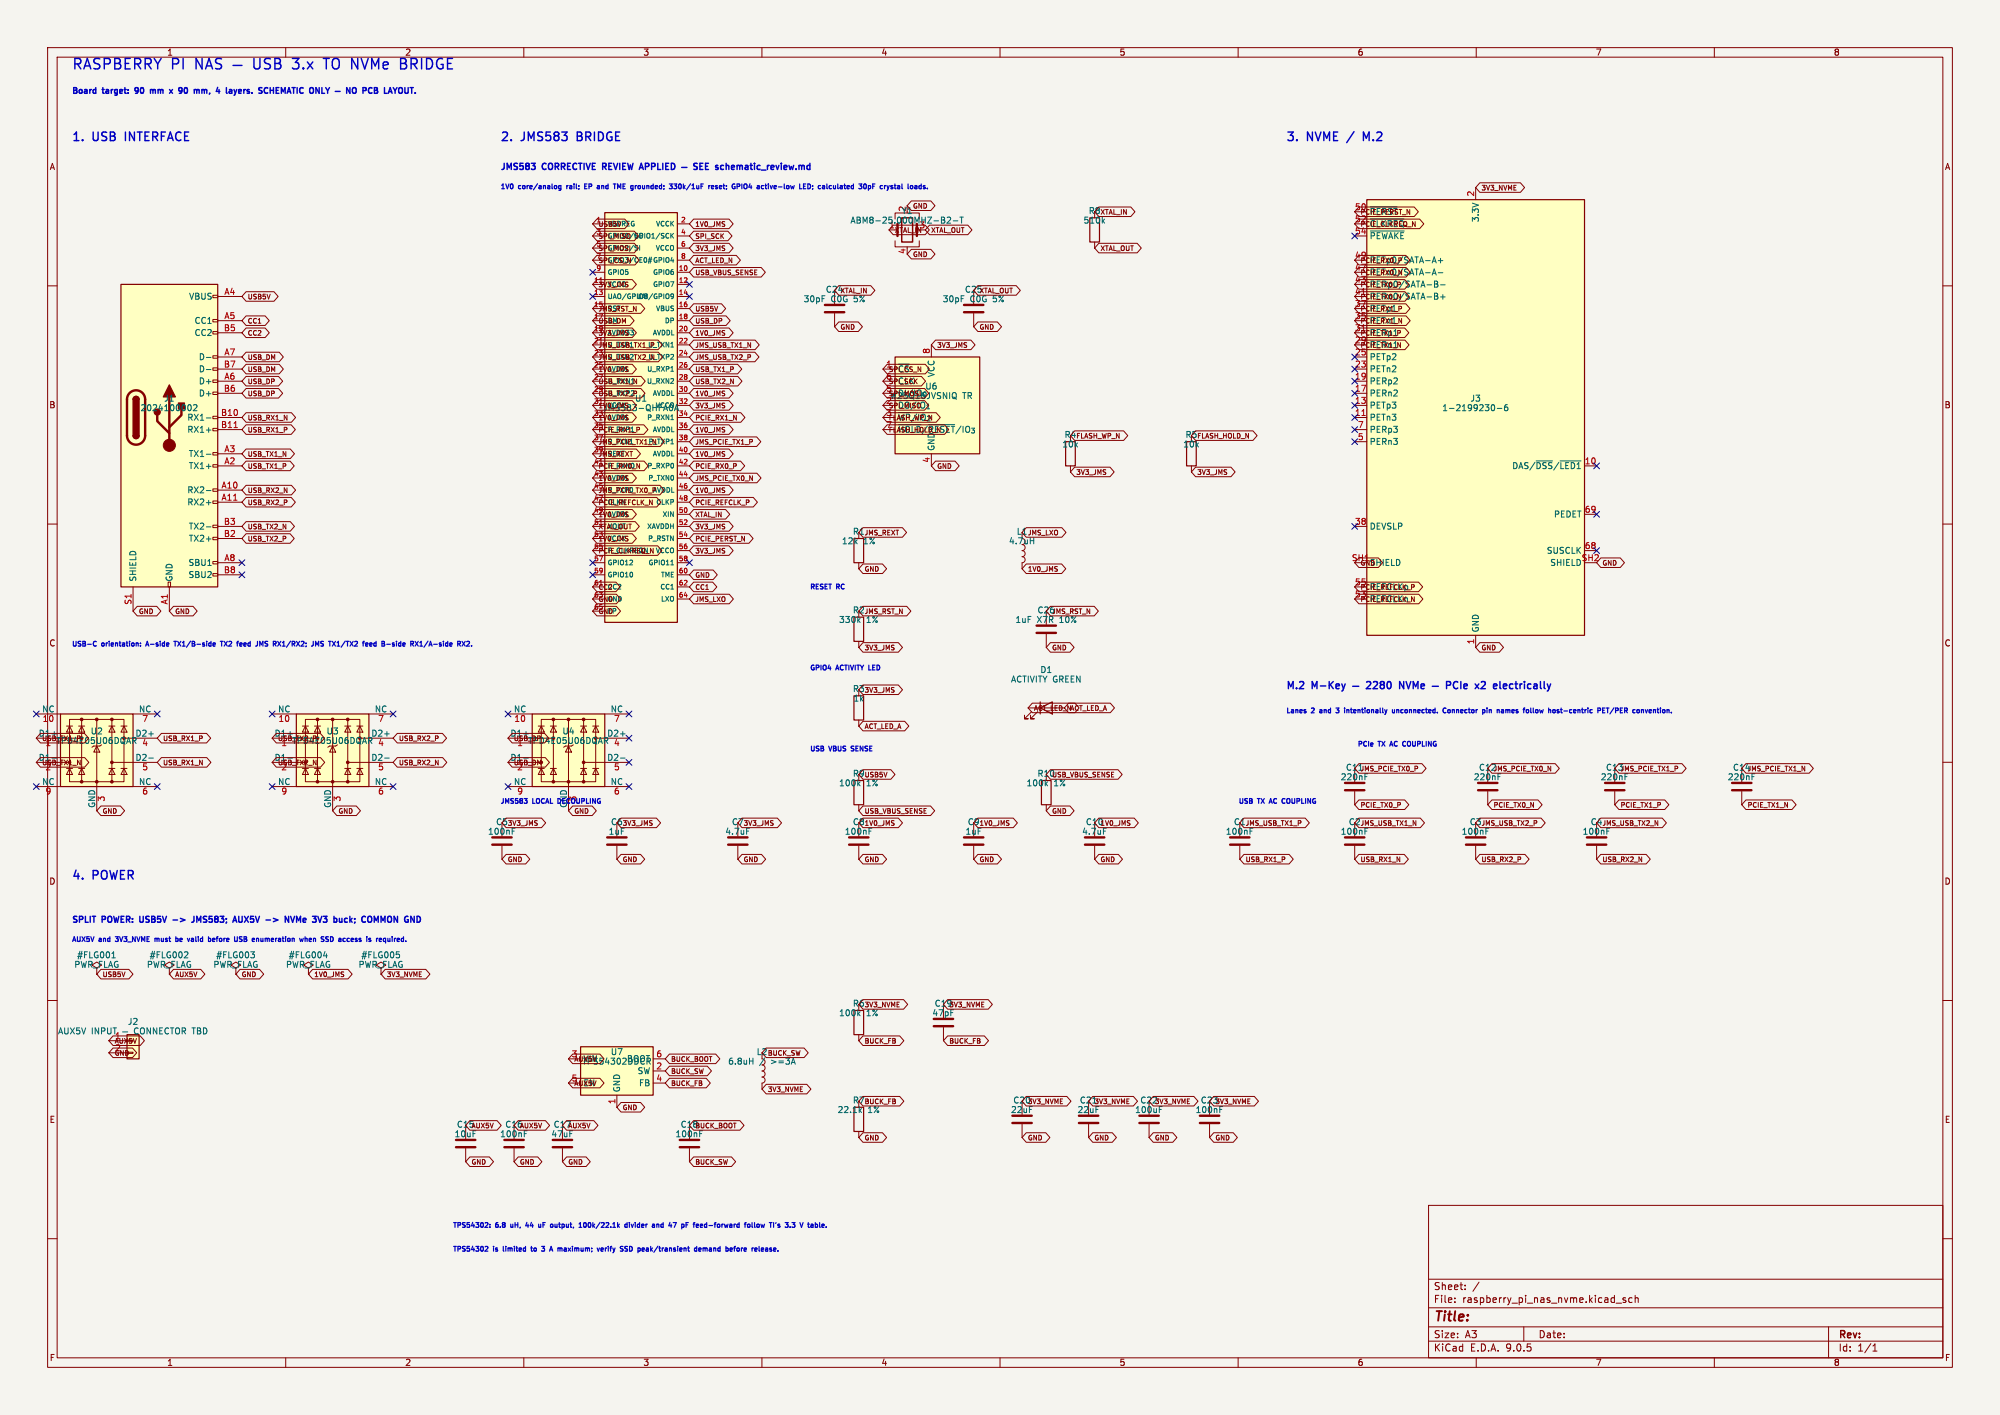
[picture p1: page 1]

RASPBERRY PI NAS þÿ USB 3.x TO NVMe BRIDGE

JMS583 CORRECTIVE REVIEW APPLIED þÿ SEE schematic_review.md

3 Y1 ABM8-25.000MHZ-B2-T VDDREG 1 GPIO0/SO 3 GPIO2/SI 5 GPIO3/CE0# 7 GPIO5 9 VCCO 11 UAO/GPIO8 13 RST 15 DM 17 AVDD33 19 U_TXP1 21 U_TXN2 23 AVDDL 25 U_RXN1 27 U_RXP2 29 VCCK 31 AVDDL 33 P_RXP1 35 P_TXN1 37 REXT 39 P_RXN0 41 AVDDL 43 P_TXP0 45 CLKN 47 AVDDL 49 XOUT 51 VCCK 53 P_CLKREQN 55 GPIO12 57 GPIO10 59 CC2 61 GND 63 EP 65

1 DAS/~{DSS}/~{LED1} 10 PEDET 69 SUSCLK 68 SHIELDSH2

PCIe TX AC COUPLING

USB TX AC COUPLING

J2 AUX5V INPUT þÿ CONNECTOR TBD

Id: 1/1 Title: File: raspberry_pi_nas_nvme.kicad_sch Sheet: / C16
AUX5V

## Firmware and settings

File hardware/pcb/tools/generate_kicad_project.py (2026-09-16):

"""Generate the repository-local reviewed KiCad 9 schematic.

The generator deliberately embeds every schematic symbol so the design can be
parsed in a clean KiCad installation while exact-part libraries remain local.
Run from the repository root with Python 3.11+.
"""

from __future__ import annotations

import json
import re
import shutil
import uuid
from pathlib import Path


ROOT = Path(__file__).resolve().parents[3]
PCB = ROOT / "hardware" / "pcb"
KICAD = PCB / "kicad"
SYMLIB = PCB / "libraries" / "symbols" / "RaspberryPiNAS_Parts.kicad_sym"
FPLIB = PCB / "libraries" / "footprints" / "RaspberryPiNAS.pretty"
MODELS = PCB / "libraries" / "3dmodels"
KICAD_SHARE = Path(r"C:\Program Files\KiCad\9.0\share\kicad")
PROJECT = "raspberry_pi_nas_nvme"


def uid() -> str:
    return str(uuid.uuid4())


def sexp_blocks(text: str, form: str, top_depth: int = 1) -> dict[str, str]:
    """Return named S-expression blocks at the requested parenthesis depth."""
    out: dict[str, str] = {}
    i = 0
    depth = 0
    in_string = False
    escaped = False
    marker = f'({form} "'
    while i < len(text):
        ch = text[i]
        if in_string:
            if escaped:
                escaped = False
            elif ch == "\\":
                escaped = True
            elif ch == '"':
                in_string = False
            i += 1
            continue
        if ch == '"':
            in_string = True
            i += 1
            continue
        if ch == "(":
            if depth == top_depth and text.startswith(marker, i):
                name_start = i + len(marker)
                name_end = text.find('"', name_start)
                name = text[name_start:name_end]
                start = i
                level = 0
                j = i
                quoted = False
                esc = False
                while j < len(text):
                    c = text[j]
                    if quoted:
                        if esc:
                            esc = False
                        elif c == "\\":
                            esc = True
                        elif c == '"':
                            quoted = False
                    else:
                        if c == '"':
                            quoted = True
                        elif c == "(":
                            level += 1
                        elif c == ")":
                            level -= 1
                            if level == 0:
                                out[name] = text[start : j + 1]
                                i = j + 1
                                break
                    j += 1
                continue
            depth += 1
        elif ch == ")":
            depth -= 1
        i += 1
    return out


def prefix_top_symbol(block: str, lib_id: str) -> str:
    return re.sub(r'^\(symbol "[^"]+"', f'(symbol "{lib_id}"', block, count=1)


def pin_records(block: str) -> dict[str, tuple[float, float, int, str]]:
    pins: dict[str, tuple[float, float, int, str]] = {}
    for match in re.finditer(r"\(pin\s+(\w+)\s+\w+", block):
        start = match.start()
        level = 0
        quoted = False
        escaped = False
        end = start
        for end in range(start, len(block)):
            ch = block[end]
            if quoted:
                if escaped:
                    escaped = False
                elif ch == "\\":
                    escaped = True
                elif ch == '"':
                    quoted = False
            else:
                if ch == '"':
                    quoted = True
                elif ch == "(":
                    level += 1
                elif ch == ")":
                    level -= 1
                    if level == 0:
                        break
        pin = block[start : end + 1]
        at = re.search(r"\(at\s+([-0-9.]+)\s+([-0-9.]+)(?:\s+([-0-9.]+))?\)", pin)
        number = re.search(r'\(number\s+"([^"]+)"', pin)
        if at and number:
            pins.setdefault(
                number.group(1),
                (float(at.group(1)), float(at.group(2)), int(float(at.group(3) or 0)), match.group(1)),
            )
    return pins


def make_flash_symbol() -> str:
    source = (KICAD_SHARE / "symbols" / "Memory_Flash.kicad_sym").read_text(encoding="utf-8")
    base = sexp_blocks(source, "symbol")["W25Q32JVSS"]
    base = base.replace("W25Q32JVSS", "W25Q16JVSNIQ")
    base = base.replace("32Mbit / 4MiB", "16Mbit / 2MiB")
    base = re.sub(
        r'http://www\.winbond\.com/resource-files/w25q32jv%20revg%2003272018%20plus\.pdf',
        "https://www.winbond.com/hq/support/documentation/levelOne.jsp?__locale=en&DocNo=DA00-W25Q16JV.1",
        base,
    )
    base = base.replace(
        "Package_SO:SOIC-8_5.3x5.3mm_P1.27mm",
        "RaspberryPiNAS:Winbond_W25Q16JVSNIQ_SOIC8_150mil",
    )
    base = base.replace("SOIC-8 (208 mil)", "SOIC-8 (150 mil)")
    return base


def snap_symbol_pins(block: str, grid: float = 1.27) -> str:
    def repl(match: re.Match[str]) -> str:
        x = round(float(match.group(2)) / grid) * grid
        y = round(float(match.group(3)) / grid) * grid
        return f"{match.group(1)}{x:g} {y:g}{match.group(4) or ''})"
    return re.sub(
        r"(\(pin\s+\w+\s+\w+\s*\(at\s+)([-0-9.]+)\s+([-0-9.]+)(\s+[-0-9.]+)?\)",
        repl,
        block,
    )


def prepare_libraries() -> dict[str, str]:
    local = SYMLIB.read_text(encoding="utf-8")
    existing = sexp_blocks(local, "symbol")
    changed = False
    if "W25Q16JVSSIQ" in existing:
        local = local.replace(existing["W25Q16JVSSIQ"], "")
        changed = True
    if "JMicron_JMS583-QHFA0A" in existing:
        repaired = snap_symbol_pins(existing["JMicron_JMS583-QHFA0A"])
        local = local.replace(existing["JMicron_JMS583-QHFA0A"], repaired)
        changed = True
    if "TE_1-2199230-6" in existing:
        # A connector does not actively drive the endpoint; passive electrical
        # types prevent false output/output ERC while retaining exact names/numbers.
        repaired = re.sub(r"\(pin (?:input|output|bidirectional) ", "(pin passive ", existing["TE_1-2199230-6"])
        local = local.replace(existing["TE_1-2199230-6"], repaired)
        changed = True
    additions = []
    if 'symbol "W25Q16JVSNIQ"' not in local:
        additions.append(make_flash_symbol())
    if additions:
        close = local.rfind(")")
        local = local[:close].rstrip() + "\n\t" + "\n\t".join(a.replace("\n", "\n\t") for a in additions) + "\n)\n"
        changed = True
    if changed:
        SYMLIB.write_text(local, encoding="utf-8")

    FPLIB.mkdir(parents=True, exist_ok=True)
    MODELS.mkdir(parents=True, exist_ok=True)
    src_fp = KICAD_SHARE / "footprints" / "Package_SO.pretty" / "SOIC-8_3.9x4.9mm_P1.27mm.kicad_mod"
    fp_text = src_fp.read_text(encoding="utf-8")
    fp_text = re.sub(r'^\(footprint "[^"]+"', '(footprint "Winbond_W25Q16JVSNIQ_SOIC8_150mil"', fp_text, count=1)
    fp_text = fp_text.replace(
        "${KICAD9_3DMODEL_DIR}/Package_SO.3dshapes/SOIC-8_3.9x4.9mm_P1.27mm.step",
        "${KIPRJMOD}/../libraries/3dmodels/SOIC-8_3.9x4.9mm_P1.27mm.step",
    )
    (FPLIB / "Winbond_W25Q16JVSNIQ_SOIC8_150mil.kicad_mod").write_text(fp_text, encoding="utf-8")
    src_step = KICAD_SHARE / "3dmodels" / "Package_SO.3dshapes" / "SOIC-8_3.9x4.9mm_P1.27mm.step"
    if src_step.exists():
        shutil.copyfile(src_step, MODELS / src_step.name)

    # Existing exact footprints were prepared before the project moved one level down.
    for footprint in FPLIB.glob("*.kicad_mod"):
        text = footprint.read_text(encoding="utf-8")
        text = text.replace("${KIPRJMOD}/libraries/3dmodels/", "${KIPRJMOD}/../libraries/3dmodels/")
        footprint.write_text(text, encoding="utf-8")

    local_blocks = sexp_blocks(SYMLIB.read_text(encoding="utf-8"), "symbol")
    return local_blocks


def global_symbol(lib: str, name: str) -> str:
    text = (KICAD_SHARE / "symbols" / f"{lib}.kicad_sym").read_text(encoding="utf-8")
    return sexp_blocks(text, "symbol")[name]


class Schematic:
    def __init__(self, symbol_blocks: dict[str, str]):
        self.root_uuid = uid()
        self.symbol_blocks = symbol_blocks
        self.items: list[str] = []
        self.used_libs: set[str] = set()
        self.components: dict[str, dict] = {}
        self.label_keys: set[tuple[float, float, str]] = set()

    def add_text(self, value: str, x: float, y: float, size: float = 1.5, bold: bool = False) -> None:
        value = value.replace("\\", "\\\\").replace('"', '\\"').replace("\n", "\\n")
        self.items.append(
            f'''\t(text "{value}"
\t\t(exclude_from_sim no)
\t\t(at {x:g} {y:g} 0)
\t\t(effects (font (size {size:g} {size:g}) (thickness 0.3){" (bold yes)" if bold else ""}) (justify left bottom))
\t\t(uuid "{uid()}")
\t)'''
        )

    def add_symbol(
        self,
        lib_id: str,
        ref: str,
        value: str,
        x: float,
        y: float,
        footprint: str = "",
        datasheet: str = "",
        description: str = "",
        in_bom: bool = True,
        on_board: bool = True,
        dnp: bool = False,
        property_y_shift: float = 0.0,
    ) -> None:
        x = round(x / 1.27) * 1.27
        y = round(y / 1.27) * 1.27
        block = self.symbol_blocks[lib_id]
        pins = pin_records(block)
        comp_uuid = uid()
        self.used_libs.add(lib_id)
        self.components[ref] = {"x": x, "y": y, "pins": pins}
        pin_entries = "\n".join(f'\t\t(pin "{n}" (uuid "{uid()}"))' for n in pins)
        esc = lambda s: s.replace("\\", "\\\\").replace('"', '\\"')
        self.items.append(
            f'''\t(symbol
\t\t(lib_id "{lib_id}")
\t\t(at {x:g} {y:g} 0)
\t\t(unit 1)
\t\t(exclude_from_sim no)
\t\t(in_bom {"yes" if in_bom else "no"})
\t\t(on_board {"yes" if on_board else "no"})
\t\t(dnp {"yes" if dnp else "no"})
\t\t(uuid "{comp_uuid}")
\t\t(property "Reference" "{esc(ref)}" (at {x:g} {y-4+property_y_shift:g} 0) (effects (font (size 1.27 1.27))))
\t\t(property "Value" "{esc(value)}" (at {x:g} {y-2+property_y_shift:g} 0) (effects (font (size 1.27 1.27))))
\t\t(property "Footprint" "{esc(footprint)}" (at {x:g} {y:g} 0) (effects (font (size 1.27 1.27)) (hide yes)))
\t\t(property "Datasheet" "{esc(datasheet)}" (at {x:g} {y:g} 0) (effects (font (size 1.27 1.27)) (hide yes)))
\t\t(property "Description" "{esc(description)}" (at {x:g} {y:g} 0) (effects (font (size 1.27 1.27)) (hide yes)))
{pin_entries}
\t\t(instances (project "{PROJECT}" (path "/{self.root_uuid}" (reference "{ref}") (unit 1))))
\t)'''
        )

    def point(self, ref: str, pin: str) -> tuple[float, float]:
        comp = self.components[ref]
        px, py, _rot, _kind = comp["pins"][str(pin)]
        return round(comp["x"] + px, 4), round(comp["y"] - py, 4)

    def label_pin(self, ref: str, pin: str, net: str) -> None:
        x, y = self.point(ref, pin)
        key = (x, y, net)
        if key in self.label_keys:
            return
        self.label_keys.add(key)
        # Point labels away from the symbol body. Pin rotation describes the
        # direction from the connection point into the symbol, so the label
        # uses the opposite direction for clear, outward-facing text.
        pin_rotation = self.components[ref]["pins"][str(pin)][2]
        label_rotation = (pin_rotation + 180) % 360 if pin_rotation in (0, 180) else 0
        self.items.append(
            f'''\t(global_label "{net}"
\t\t(shape bidirectional)
\t\t(at {x:g} {y:g} {label_rotation:g})
\t\t(effects (font (size 1.0 1.0)) (justify left))
\t\t(uuid "{uid()}")
\t\t(property "Intersheetrefs" "${{INTERSHEET_REFS}}" (at {x:g} {y:g} 0) (effects (font (size 1.0 1.0)) (hide yes)))
\t)'''
        )

    def no_connect_pin(self, ref: str, pin: str) -> None:
        x, y = self.point(ref, pin)
        self.items.append(f'\t(no_connect (at {x:g} {y:g}) (uuid "{uid()}"))')

    def connect(self, ref: str, mapping: dict[str, str]) -> None:
        for pin, net in mapping.items():
            self.label_pin(ref, str(pin), net)
        mapped = {str(p) for p in mapping}
        seen_points: set[tuple[float, float]] = set()
        for pin, rec in self.components[ref]["pins"].items():
            if pin in mapped or rec[3] == "no_connect":
                continue
            point = self.point(ref, pin)
            if point not in seen_points:
                self.no_connect_pin(ref, pin)
                seen_points.add(point)

    def render(self) -> str:
        libs = []
        for lib_id in sorted(self.used_libs):
            libs.append(prefix_top_symbol(self.symbol_blocks[lib_id], lib_id).replace("\n", "\n\t\t"))
        libraries_text = "\n\t\t".join(libs)
        items_text = "\n".join(self.items)
        return f'''(kicad_sch
\t(version 20250114)
\t(generator "eeschema")
\t(generator_version "9.0")
\t(uuid "{self.root_uuid}")
\t(paper "A3")
\t(lib_symbols
\t\t{libraries_text}
\t)
{items_text}
\t(sheet_instances (path "/" (page "1")))
\t(embedded_fonts no)
)\n'''


def build_schematic(local: dict[str, str]) -> str:
    blocks: dict[str, str] = {}
    for name, block in local.items():
        blocks[f"RaspberryPiNAS_Parts:{name}"] = block
    for name in ("R", "C", "L", "LED"):
        blocks[f"Device:{name}"] = global_symbol("Device", name)
    blocks["Connector_Generic:Conn_01x02"] = global_symbol("Connector_Generic", "Conn_01x02")
    blocks["power:PWR_FLAG"] = global_symbol("power", "PWR_FLAG")

    s = Schematic(blocks)
    s.add_text("RASPBERRY PI NAS — USB 3.x TO NVMe BRIDGE", 15, 15, 2.2, True)
    s.add_text("Board target: 90 mm x 90 mm, 4 layers. SCHEMATIC ONLY — NO PCB LAYOUT.", 15, 20, 1.2)
    s.add_text("1. USB INTERFACE", 15, 30, 1.8, True)
    s.add_text("2. JMS583 BRIDGE", 105, 30, 1.8, True)
    s.add_text("3. NVME / M.2", 270, 30, 1.8, True)
    s.add_text("4. POWER", 15, 185, 1.8, True)

    # USB receptacle and three four-channel ESD arrays (all SS pairs plus USB2 pair).
    s.add_symbol("RaspberryPiNAS_Parts:Molex_2024100002", "J1", "2024100002", 35, 88,
                 "RaspberryPiNAS:Molex_2024100002", "https://www.molex.com/en-us/products/part-detail/2024100002")
    usb = {
        "A1": "GND", "A12": "GND", "B1": "GND", "B12": "GND", "S1": "GND",
        "A4": "USB5V", "A9": "USB5V", "B4": "USB5V", "B9": "USB5V",
        "A5": "CC1", "B5": "CC2", "A6": "USB_DP", "B6": "USB_DP", "A7": "USB_DM", "B7": "USB_DM",
        "A2": "USB_TX1_P", "A3": "USB_TX1_N", "B11": "USB_RX1_P", "B10": "USB_RX1_N",
        "B2": "USB_TX2_P", "B3": "USB_TX2_N", "A11": "USB_RX2_P", "A10": "USB_RX2_N",
    }
    s.connect("J1", usb)

    for ref, x, nets in (
        ("U2", 20, ("USB_TX1_P", "USB_TX1_N", "USB_RX1_P", "USB_RX1_N")),
        ("U3", 70, ("USB_TX2_P", "USB_TX2_N", "USB_RX2_P", "USB_RX2_N")),
        ("U4", 120, ("USB_DP", "USB_DM", None, None)),
    ):
        s.add_symbol("RaspberryPiNAS_Parts:TPD4E05U06DQAR", ref, "TPD4E05U06DQAR", x, 158,
                     "RaspberryPiNAS:TPD4E05U06DQAR_DQA0010A", "https://www.ti.com/lit/ds/symlink/tpd4e05u06.pdf")
        esd_map = {"1": nets[0], "2": nets[1], "3": "GND", "8": "GND"}
        if nets[2] is not None:
            esd_map.update({"4": nets[2], "5": nets[3]})
        s.connect(ref, esd_map)

    # JMS583 bridge. USB-C orientation mapping crosses receptacle TX into JMS RX and vice versa.
    s.add_symbol("RaspberryPiNAS_Parts:JMicron_JMS583-QHFA0A", "U1", "JMS583-QHFA0A", 135, 88,
                 "RaspberryPiNAS:JMicron_JMS583-QHFA0A", "../libraries/datasheets/JMicron_JMS583_datasheet_rev2.1.pdf")
    jms = {
        # VDDREG and VBUS are USB-powered. LXO/L1 generate the 1.0 V core/analog rail.
        "1": "USB5V", "2": "1V0_JMS", "3": "SPI_MISO", "4": "SPI_SCK", "5": "SPI_MOSI",
        "6": "3V3_JMS", "7": "SPI_CS_N", "8": "ACT_LED_N", "10": "USB_VBUS_SENSE",
        "11": "3V3_JMS", "15": "JMS_RST_N", "16": "USB5V",
        "17": "USB_DM", "18": "USB_DP", "19": "3V3_JMS", "20": "1V0_JMS",
        "21": "JMS_USB_TX1_P", "22": "JMS_USB_TX1_N", "23": "JMS_USB_TX2_N", "24": "JMS_USB_TX2_P",
        "25": "1V0_JMS", "26": "USB_TX1_P", "27": "USB_TX1_N", "28": "USB_TX2_N", "29": "USB_TX2_P",
        "30": "1V0_JMS", "31": "1V0_JMS", "32": "3V3_JMS", "33": "1V0_JMS",
        "34": "PCIE_RX1_N", "35": "PCIE_RX1_P", "36": "1V0_JMS", "37": "JMS_PCIE_TX1_N", "38": "JMS_PCIE_TX1_P",
        "39": "JMS_REXT", "40": "1V0_JMS", "41": "PCIE_RX0_N", "42": "PCIE_RX0_P", "43": "1V0_JMS",
        "44": "JMS_PCIE_TX0_N", "45": "JMS_PCIE_TX0_P", "46": "1V0_JMS", "47": "PCIE_REFCLK_N", "48": "PCIE_REFCLK_P",
        "49": "1V0_JMS", "50": "XTAL_IN", "51": "XTAL_OUT", "52": "3V3_JMS", "53": "1V0_JMS",
        "54": "PCIE_PERST_N", "55": "PCIE_CLKREQ_N", "56": "3V3_JMS", "60": "GND",
        "61": "CC2", "62": "CC1", "63": "GND", "64": "JMS_LXO", "65": "GND",
    }
    s.connect("U1", jms)

    # USB transmitter coupling capacitors are on JMS TX outputs only.
    for i, (raw, net) in enumerate((
        ("JMS_USB_TX1_P", "USB_RX1_P"), ("JMS_USB_TX1_N", "USB_RX1_N"),
        ("JMS_USB_TX2_P", "USB_RX2_P"), ("JMS_USB_TX2_N", "USB_RX2_N")), 1):
        ref = f"C{i}"
        s.add_symbol("Device:C", ref, "100nF", 260 + (i - 1) * 25, 177,
                     "Capacitor_SMD:C_0603_1608Metric_Pad1.08x0.95mm_HandSolder")
        s.connect(ref, {"1": raw, "2": net})

    s.add_symbol("RaspberryPiNAS_Parts:Abracon_ABM8-25.000MHZ-B2-T", "Y1", "ABM8-25.000MHZ-B2-T", 190, 48,
                 "RaspberryPiNAS:Abracon_ABM8-25.000MHZ-B2-T", "../libraries/datasheets/Abracon_ABM8_datasheet.pdf")
    s.connect("Y1", {"1": "XTAL_IN", "2": "GND", "3": "XTAL_OUT", "4": "GND"})
    # ABM8 CL=18 pF. With 3 pF estimated combined pin/trace stray, equal 30 pF
    # capacitors give CL = (30 pF * 30 pF)/(30 pF + 30 pF) + 3 pF = 18 pF.
    for ref, net, x in (("C24", "XTAL_IN", 175), ("C25", "XTAL_OUT", 205)):
        s.add_symbol("Device:C", ref, "30pF C0G 5%", x, 65,
                     "Capacitor_SMD:C_0603_1608Metric_Pad1.08x0.95mm_HandSolder")
        s.connect(ref, {"1": net, "2": "GND"})
    s.add_symbol("Device:R", "R8", "510k", 230, 48,
                 "Resistor_SMD:R_0603_1608Metric_Pad0.98x0.95mm_HandSolder")
    s.connect("R8", {"1": "XTAL_IN", "2": "XTAL_OUT"})

    s.add_symbol("RaspberryPiNAS_Parts:W25Q16JVSNIQ", "U6", "W25Q16JVSNIQ TR", 195, 85,
                 "RaspberryPiNAS:Winbond_W25Q16JVSNIQ_SOIC8_150mil",
                 "https://www.winbond.com/hq/support/documentation/levelOne.jsp?__locale=en&DocNo=DA00-W25Q16JV.1")
    s.connect("U6", {"1": "SPI_CS_N", "2": "SPI_MISO", "3": "FLASH_WP_N", "4": "GND",
                     "5": "SPI_MOSI", "6": "SPI_SCK", "7": "FLASH_HOLD_N", "8": "3V3_JMS"})

    for ref, net, x in (("R4", "FLASH_WP_N", 225), ("R5", "FLASH_HOLD_N", 250)):
        s.add_symbol("Device:R", ref, "10k", x, 95, "Resistor_SMD:R_0603_1608Metric_Pad0.98x0.95mm_HandSolder")
        s.connect(ref, {"1": net, "2": "3V3_JMS"})

    s.add_symbol("Device:R", "R1", "12k 1%", 180, 115, "Resistor_SMD:R_0603_1608Metric_Pad0.98x0.95mm_HandSolder")
    s.connect("R1", {"1": "JMS_REXT", "2": "GND"})
    s.add_symbol("Device:L", "L1", "4.7uH", 215, 115, "Inductor_SMD:L_1210_3225Metric_Pad1.42x2.65mm_HandSolder")
    s.connect("L1", {"1": "JMS_LXO", "2": "1V0_JMS"})
    # RST is active low. The datasheet specifies 120-500 ms to reach 1.77 V.
    # For 3.3 V, 330k/1uF reaches 1.77 V at -RC*ln(1-1.77/3.3) = 254 ms nominal.
    s.add_symbol("Device:R", "R2", "330k 1%", 180, 132, "Resistor_SMD:R_0603_1608Metric_Pad0.98x0.95mm_HandSolder")
    s.connect("R2", {"1": "JMS_RST_N", "2": "3V3_JMS"})
    s.add_symbol("Device:C", "C26", "1uF X7R 10%", 220, 132,
                 "Capacitor_SMD:C_0603_1608Metric_Pad1.08x0.95mm_HandSolder")
    s.connect("C26", {"1": "JMS_RST_N", "2": "GND"})
    s.add_text("RESET RC", 170, 124, 1.0, True)
    s.add_symbol("Device:R", "R3", "1k", 180, 149, "Resistor_SMD:R_0603_1608Metric_Pad0.98x0.95mm_HandSolder")
    s.connect("R3", {"1": "3V3_JMS", "2": "ACT_LED_A"})
    s.add_symbol("Device:LED", "D1", "ACTIVITY GREEN", 220, 149,
                 "LED_SMD:LED_0603_1608Metric_Pad1.05x0.95mm_HandSolder", property_y_shift=-4)
    s.connect("D1", {"1": "ACT_LED_N", "2": "ACT_LED_A"})
    s.add_text("GPIO4 ACTIVITY LED", 170, 141, 1.0, True)

    # GPIO4 is the default active-low activity LED output: 3V3 -> R3 -> LED A/K -> GPIO4.
    # GPIO6 receives a divided copy of USB VBUS for explicit cable-power sensing.
    s.add_symbol("Device:R", "R9", "100k 1%", 180, 166,
                 "Resistor_SMD:R_0603_1608Metric_Pad0.98x0.95mm_HandSolder")
    s.connect("R9", {"1": "USB5V", "2": "USB_VBUS_SENSE"})
    s.add_symbol("Device:R", "R10", "100k 1%", 220, 166,
                 "Resistor_SMD:R_0603_1608Metric_Pad0.98x0.95mm_HandSolder")
    s.connect("R10", {"1": "USB_VBUS_SENSE", "2": "GND"})
    s.add_text("USB VBUS SENSE", 170, 158, 1.0, True)

    # Representative local bypassing on both JMS-generated rails.
    for i, (value, net, x) in enumerate((
        ("100nF", "3V3_JMS", 105), ("1uF", "3V3_JMS", 130), ("4.7uF", "3V3_JMS", 155),
        ("100nF", "1V0_JMS", 180), ("1uF", "1V0_JMS", 205), ("4.7uF", "1V0_JMS", 230)), 1):
        ref = f"C{i + 4}"
        s.add_symbol("Device:C", ref, value, x, 177, "Capacitor_SMD:C_0603_1608Metric_Pad1.08x0.95mm_HandSolder")
        s.connect(ref, {"1": net, "2": "GND"})
    s.add_text("JMS583 LOCAL DECOUPLING", 105, 169, 1.0, True)
    s.add_text("USB TX AC COUPLING", 260, 169, 1.0, True)

    s.add_text("JMS583 CORRECTIVE REVIEW APPLIED — SEE schematic_review.md", 105, 36, 1.3, True)
    s.add_text("1V0 core/analog rail; EP and TME grounded; 330k/1uF reset; GPIO4 active-low LED; calculated 30pF crystal loads.", 105, 40, 1.0)
    s.add_text("USB-C orientation: A-side TX1/B-side TX2 feed JMS RX1/RX2; JMS TX1/TX2 feed B-side RX1/A-side RX2.", 15, 136, 1.0)
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

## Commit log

2026-09-15 Add initial KiCad NVMe carrier schematic and local libraries
    [raspberry_pi_nas_nvme.kicad_sch, raspberry_pi_nas_nvme_bom.csv]
2026-09-15 Correct JMS583 power, reset, crystal, LED, and split-supply design
    [raspberry_pi_nas_nvme.kicad_sch, raspberry_pi_nas_nvme_bom.csv]
2026-09-16 Clean up KiCad schematic presentation
    [raspberry_pi_nas_nvme.kicad_sch]
